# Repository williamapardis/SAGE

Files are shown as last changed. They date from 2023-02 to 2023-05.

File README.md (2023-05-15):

# SAGE

## SAGE ELECTRONICS

- The main SAGE electronics consist of a Red Pitaya FPGA/linux embedded controller, a custom IO PCB, a custom photodiode detector PCB, and a BME280 PCB.
- The Red Pitaya's main fuction is to provide the laser modulation signal and acquire the photodiode signal.
- The custom IO PCB has the following functions:
  - Power regulation for input voltage (usually 24V), 12V, 5V.  All are reverse protected to 40V.  Overcurrent protected. Can take input 12.1-50V.
  - Power switching on 8 channels.  PWM voltage control for each channel.
  - Two i2c pressure sensors.
  - Supplies power to laser and Red Pitaya.
  - Serial communication to Red Pitaya.
  - ESP32 microcontroller - onboard ADCs read thermistors, one onbaord DAC controls laser temperature, one onboard DAC can modulate laser (not preferred), DIO switches power channels, talks to PWM controllers for power modulation (16 on one chip, only using 8), gets time from clock, interfaces with SD Card.
-  The photodiode board contains a photodiode and a dual stage amplifier.  Amplifier resistance and capacitance can be tuned to adjust gain and filtering.
-  A custom PCB for the BME280 contains only a BME 280 on a small circular board.
     
## Custom PCBs

### [SAGE_IO PCB 17-0010](https://github.com/williamapardis/SAGE_IO/tree/main/electrical/SAGE/17-%200010%20ESP32-S3%20Control%20IO)
<table>
  <tr>
    <td>Full View PCB</td>
     <td>Zoomed View</td>
  </tr>
  <tr>
    <td></td>
    <td></td>
  </tr>
</table>

#### Load Control Voltage Selection


### [SAGE Detect PCB](https://github.com/williamapardis/SAGE/tree/main/electrical/SAGE/17-0001%20SAGE%20DETECT) 
<table>
  <tr>
    <td>Full View PCB</td>
     <td>Zoomed View</td>
  </tr>
  <tr>
    <td></td>
    <td></td>
  </tr>
</table>

### RP Adaptor PCB
<table>
  <tr>
    <td>Full View PCB</td>
     <td>Zoomed View</td>
  </tr>
  <tr>
    <td></td>
    <td></td>
  </tr>
</table>

### BME280 PCB
<table>
  <tr>
    <td>Full View PCB</td>
     <td>Zoomed View</td>
  </tr>
  <tr>
    <td></td>
    <td></td>
  </tr>
</table>

## Software

### Set Commands

#### Set Load -> SL#:$$ 
#  = 1-8 FETS
$$ = 0-1 %

#### Set Time (two options)
  sync NTP (current servers: "time.nist.gov", "0.pool.ntp.org", "1.pool.ntp.org")
    SN
  manually
    ST:YYYYMMDD:hhmmss
    
####
    
## Get Commands

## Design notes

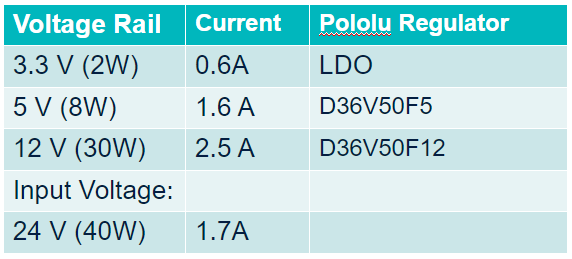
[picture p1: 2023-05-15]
electrical/SAGE/17- 0010 ESP32-S3 Control IO/import/overall totals.png

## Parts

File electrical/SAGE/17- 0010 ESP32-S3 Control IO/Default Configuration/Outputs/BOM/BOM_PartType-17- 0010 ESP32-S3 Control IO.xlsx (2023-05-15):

Quantity | Manufacturer Part # | Manufacturer | Do Not Install | Designator | Vendor | Vendor Part Number | Value | Footprints | Description
1 | DS3231S#T&R | Maxim |  | U9 |  |  |  |  | Real-Time Clock
2 | LMP2011MFX/NOPB | Texas Instruments |  | U8, U10 |  |  |  |  | Single, High Precision, Rail-to-Rail Output Operational Amplifier
1 | MAX6045BEUR | Analog Devices Inc./Maxim Integrated |  | U7 |  |  |  |  | Voltage References Precision, Low-Power, Low-Dropout, SOT23-3 Voltage References
1 | PCA9685PW,112 | NXP USA |  | U6
1 | QT PY ESP32-S3 |  | DNI | U4 | Adafruit | 5426 |  |  | WiFi Dev Board with STEMMA QT - 8 MB Flash / No PSRAM
1 | MCP4728-E/UN | Microchip |  | U3
2 | MPRLS0300YG00001B | Honeywell |  | U2, U5
1 | AP2112K-3.3TRG1 | Diodes Incorporated |  | U1 |  |  |  |  | IC REG LINEAR 3.3V 600MA SOT25
1 | ERJ-PB3B1302V | Panasonic Electronic Components |  | R11 |  |  | 13k | 0603 | Resistor, 0.1%, 1/5W
1 | ERA-3AEB163V | Panasonic Electronic Components |  | R10 |  |  | 16k | 0603 | Resistor, 0.1%, 1/10W
12 | AC0402FR-7W10KL | YAGEO |  | R3, R4, R5, R6, R7, R8, R9, R12, R21, R22, R23, R24 |  |  | 10k | 0402 | RES 10 KOHM 1% 1/8W 0402
1 | SR0402FR-7T4K7L | YAGEO |  | R2 |  |  | 4.7k | 0402 | RES 4.7K OHM 1% 1/5W 0402
9 | SR0603FR-7T100KL | YAGEO |  | R1, R13, R14, R15, R16, R17, R18, R19, R20 |  |  | 100K | 0603 | RES 100K OHM 1% 1/4W 0603
8 | BUK98150-55A/CUF | Nexperia USA |  | Q1, Q2, Q3, Q4, Q5, Q6, Q7, Q8 |  |  |  |  | N-MOSFET N-CH 55V 5.5A SOT223
1 | D36V28F5 | Pololu |  | P17 | Pololu | D36V28F5 |  |  | 5V, 3.2A Step-Down Voltage Regulator
2 | 68000-103HLF | Amphenol ICC (FCI) |  | P15, P16 |  |  |  |  | Header, 3-Pin
8 | 67997-206HLF | Amphenol ICC (FCI) |  | P7, P8, P9, P10, P11, P12, P13, P14 |  |  |  |  | Header, 3-Pin, Dual row
1 | 0022057045 | Molex |  | P6 |  |  |  |  | Connector Header Through Hole, Right Angle 4 position 0.098" (2.50mm)
1 | BM15B-SRSS-TB(LF)(SN) | JST Sales America Inc. |  | P5 |  |  |  |  | Header, 15-Pin
1 | D36V50F5 | Pololu |  | P4 | Pololu | D36V50F5 |  |  | 12V, 4.5A Step-Down Voltage Regulator5V, 5.5A Step-Down Voltage Regulator
1 | D36V50F12 | Pololu |  | P3 | digikey | 2183-4095-ND |  |  | DC DC CONVERTER 12V 54W
1 | 0430451227 | Molex |  | P2 |  |  |  |  | CONN HEADER VERT 12POS 3MM
1 | 0430450827 | Molex |  | P1 |  |  |  |  | CONN HEADER VERT 8POS 3MM
1 | 5031821852 | Molex |  | J15 |  |  |  |  | 10 (8 + 2) Position Card Connector Secure Digital - microSDâ„¢ Surface Mount, Right Angle Gold
8 | 0430450226 |  |  | J5, J6, J7, J8, J9, J10, J11, J12 |  |  |  |  | CONN HEADER VERT 2POS
2 | SM04B-SRSS-TB(LF)(SN) | JST Sales |  | J3, J4
5 | BM04B-SRSS-TB(LF)(SN) | JST Sales |  | J1, J2, J13, J14, J16
1 | NSR0320MW2T1G | onsemi |  | D9 |  |  |  |  | DIODE SCHOTTKY 20V 1A SOD323
8 | S1MLHRVG | Taiwan Semiconductor |  | D1, D2, D3, D4, D5, D6, D7, D8 |  |  |  |  | DIODE GEN PURP 1KV 1A SMA
2 | CC0603KRX7R0BB103 | YAGEO |  | C14, C15 |  |  | 10nF | 0603 | CAP CER 10000PF 100V X7R 0603
1 | CC0603KRX7R0BB222 | YAGEO |  | C13 |  |  | 2.2nF | 0603 | CAP CER 2200PF 100V X7R 0603
2 | CC0603KPX7R9BB104 | YAGEO |  | C4, C8 |  |  | 0.1uF | 0603 | CAP CER 0.1UF 50V X7R 0603
2 | AC0603KRX7R8BB105 | YAGEO |  | C2, C12 |  |  | 1uF | 0603 | CAP CER 1UF 25V X7R 0603
8 | CC0603KRX5R7BB106 | YAGEO |  | C1, C3, C5, C6, C7, C9, C10, C11 |  |  | 10uF | 0603 | CAP CER 10UF 16V X5R 0603
1 | BK-917 | MPD |  | BT |  |  |  |  | BATTERY RETAINER COIN PC PIN

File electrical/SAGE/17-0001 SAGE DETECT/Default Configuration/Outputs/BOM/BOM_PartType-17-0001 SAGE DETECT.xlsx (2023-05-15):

Do Not Install | Quantity | Designator | Manufacturer | Manufacturer Part # | Value | Description | Vendor | Vendor Part #
 | 5 | C1, C2, C3, C9, C10 |  | CC0402MRX6S7BB225 | 2.2uF | 2.2 µF ±20% 16V Ceramic Capacitor X6S 0402 (1005 Metric)
 | 1 | C4 |  | CC0402MRX6S5BB475 | 4.7uF | 4.7 µF ±20% 6.3V Ceramic Capacitor X6S 0402 (1005 Metric)
 | 1 | C5 |  | CC0402KPX5R8BB105 | 1uF | 1 µF ±10% 25V Ceramic Capacitor X5R 0402 (1005 Metric)
 | 1 | C6 | YAGEO | CC0603ZPY5V9BB104 | 100nF | 0.1 µF -20%, +80% 50V Ceramic Capacitor Y5V (F) 0603 (1608 Metric)
DNI | 1 | C7 |  |  | 100pF | Capacitor (Semiconductor SIM Model)
 | 1 | C8 | YAGEO | CC0603JPNPO9BN101 | 100pF | 100 pF ±5% 50V Ceramic Capacitor C0G, NP0 0603 (1608 Metric)
 | 1 | D1 | Lite-On Inc. | LTST-C191TGKT |  | Green 525nm LED Indication - Discrete 3.2V 0603 (1608 Metric)
DNI | 1 | D2
 | 1 | J2 | Linx Technologies Inc. | CONMMCX001-SMD |  | MMCX Connector Receptacle, Female Socket 50Ohm Surface Mount Solder
 | 1 | P1 | JST Sales America Inc. | BM04B-SRSS-TB(LF)(SN) |  | Header, 4-PinConnector Header Surface Mount 4 position 0.039" (1.00mm)
 | 4 | R1, R2, R3, R5 | YAGEO | RT0603BRD07100KL | 100k | 100 kOhms ±0.1% 0.1W, 1/10W Chip Resistor 0603 (1608 Metric) Thin Film
 | 1 | R4 | YAGEO | RT0603BRD07100RL | 100 | 100 Ohms ±0.1% 0.1W, 1/10W Chip Resistor 0603 (1608 Metric) Thin Film
 | 1 | R6 | YAGEO | RT0603BRE0750RL | 50 | 50 Ohms ±0.1% 0.1W, 1/10W Chip Resistor 0603 (1608 Metric) Thin Film
DNI | 2 | R8, R10 |  |  | 100k | Resistor
 | 1 | R9 | YAGEO | RT0603BRD0719K1L | 19.1k | 19.1 kOhms ±0.1% 0.1W, 1/10W Chip Resistor 0603 (1608 Metric) Thin Film
 | 1 | R11 | YAGEO | RC0402FR-070RL | 0 | 0 Ohms Jumper Chip Resistor 0402 (1005 Metric) Moisture Resistant Thick Film
 | 1 | R12 | YAGEO | RT0603BRD071KL | 1k | 1 kOhms ±0.1% 0.1W, 1/10W Chip Resistor 0603 (1608 Metric) Thin Film
 | 1 | U1 | Texas Instruments | LM27762DSSR |  | Charge Pump Switching Regulator IC Positive and Negative (Dual Rail) Adjustable -5V, 1.5V 2 - Dual Output 250mA 12-WFDFN Exposed Pad
 | 1 | U2 | Analog Devices | ADA4528-2ARMZ-R7 |  | Zero-Drift Amplifier 2 Circuit Rail-to-Rail 8-MSOP

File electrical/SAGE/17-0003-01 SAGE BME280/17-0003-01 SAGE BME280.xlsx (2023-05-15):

Manufactuer | Part Number | Description | Designator | Footprint | Voltage | Tollerence | Quantity
Bosch Sensortec | BME280 | SENSOR PRESSURE HUMIDITY TEMP | U1 | SMD |  |  | 1
JST Sales America Inc. | BM04B-SRSS-TB(LF)(SN) | CONN HEADER SMD 4POS 1MM | J1 | SMD

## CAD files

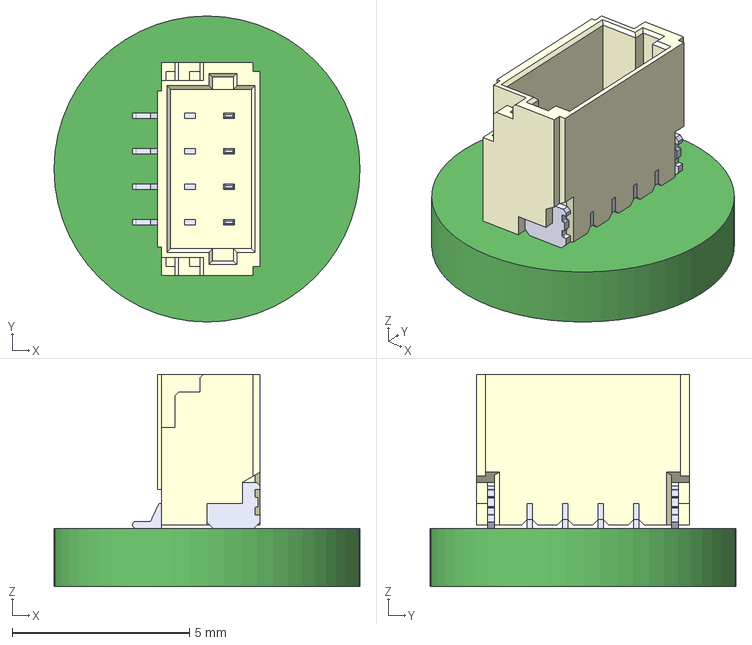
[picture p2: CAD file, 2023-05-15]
electrical/SAGE/17-0003-01 SAGE BME280/Default Configuration/Outputs/ExportSTEP/PCB1.step
8.64 x 8.64 x 6.00 mm
Board
BM04B-SRSS-TB-LF--SN---3DModel-STEP-56544

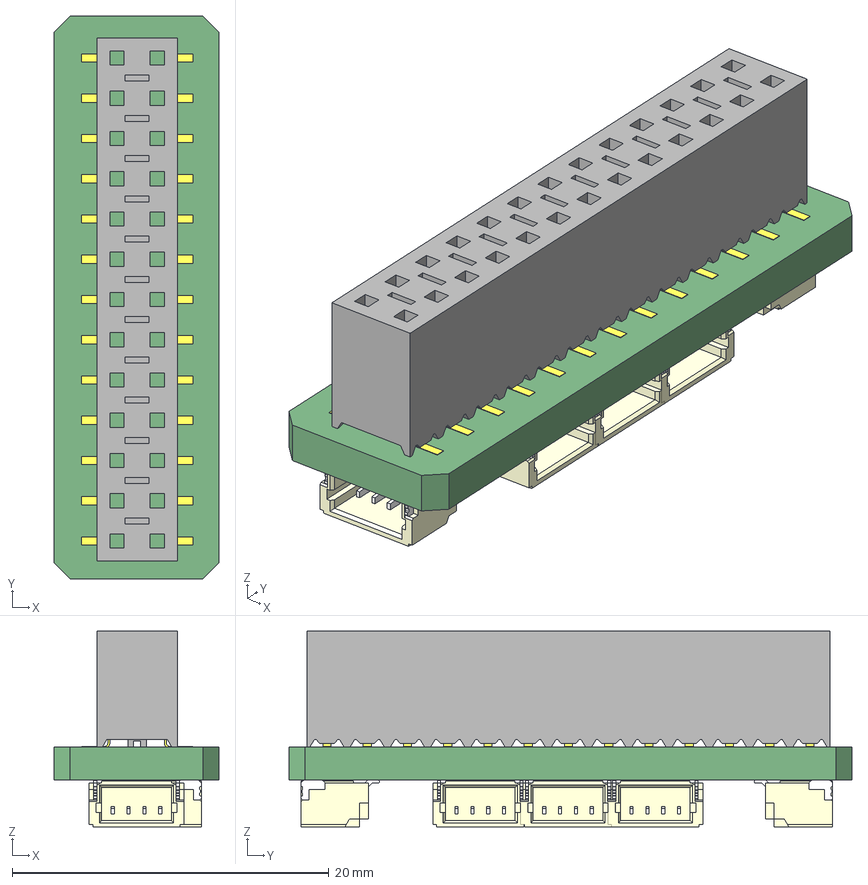
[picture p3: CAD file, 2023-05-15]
electrical/SAGE/Head Adaptor 400-0002/Default Configuration/Outputs/ExportSTEP/PCB1.step
10.4 x 35.5 x 12.4 mm
Board
SM04B-SRSS-TB(LF)(SN)--3DModel-STEP-56544 x 5
C-137-0113
SSM-113-F-DV-LC_body

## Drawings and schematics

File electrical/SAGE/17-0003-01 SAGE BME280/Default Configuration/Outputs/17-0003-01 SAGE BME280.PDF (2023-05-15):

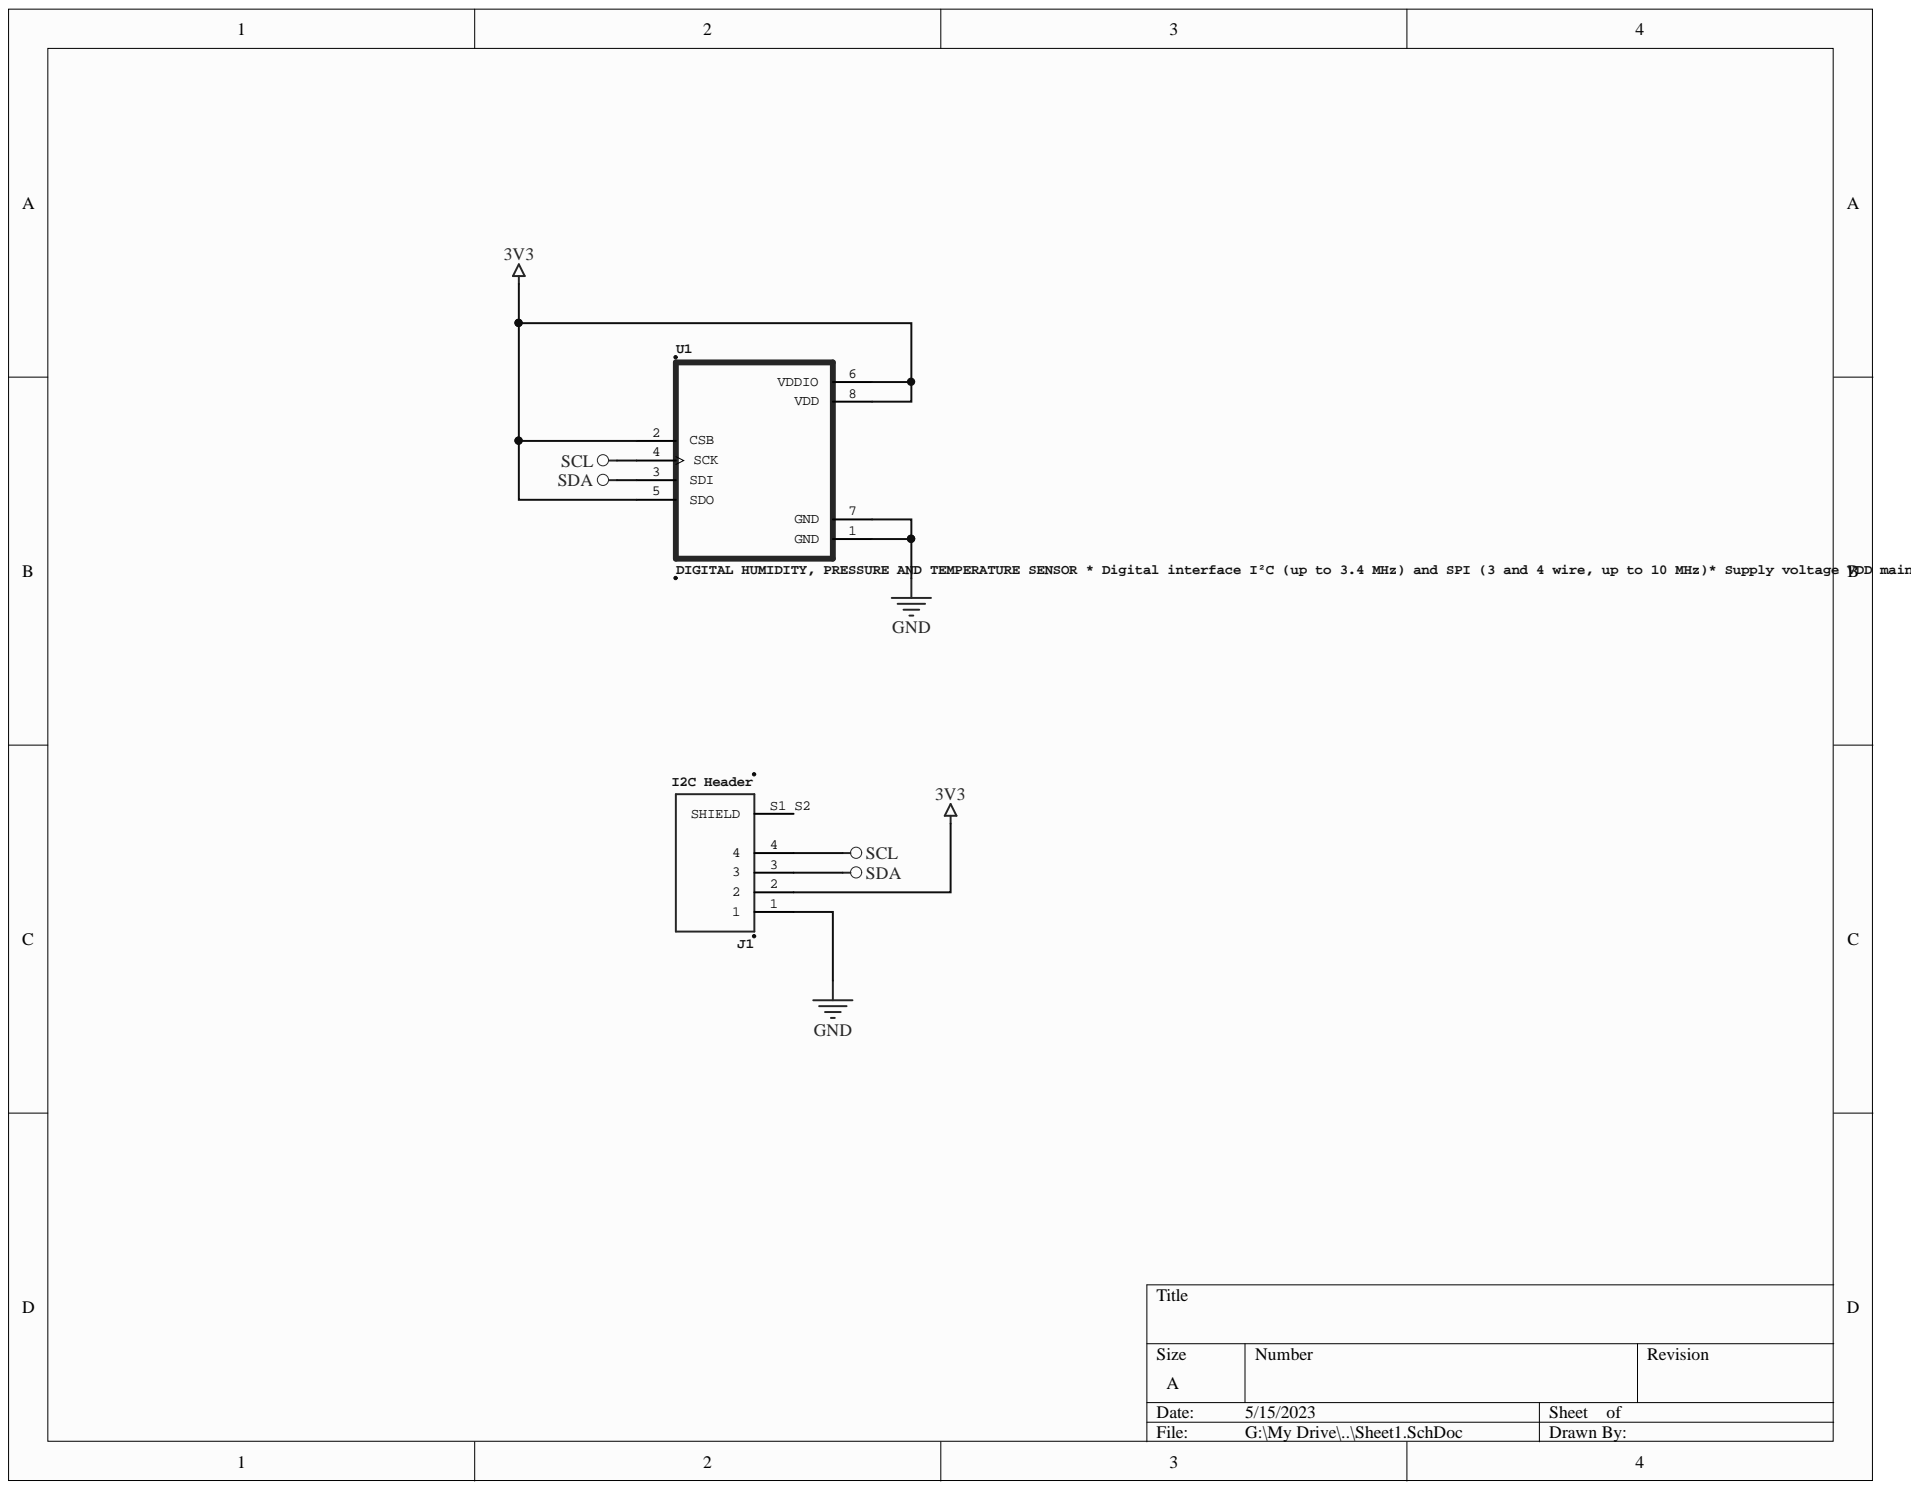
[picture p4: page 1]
Date:; Sheet of; File:; G:\My Drive\..\Sheet1.SchDoc; Drawn By:; CSB 2; SDO 5; SDI 3; SCK 4; DIGITAL HUMIDITY, PRESSURE AND TEMPERATURE SENSOR * Digital interface I²C (up to 3.4 MHz) and SPI (3 and 4 wire, up to 10 MHz)* Supply voltage VDD main supply voltage range: 1.71 V to 3.6 V*VDDIO interface voltage range: 1.2 V to 3.6 V Operating range -40…+85 °C, 0…100 % rel. humidity, 300…1100 hPa; The library has been designed by Richard Magdycz Check availability; SHIELD; I2C Header; PIJ10S1 S2

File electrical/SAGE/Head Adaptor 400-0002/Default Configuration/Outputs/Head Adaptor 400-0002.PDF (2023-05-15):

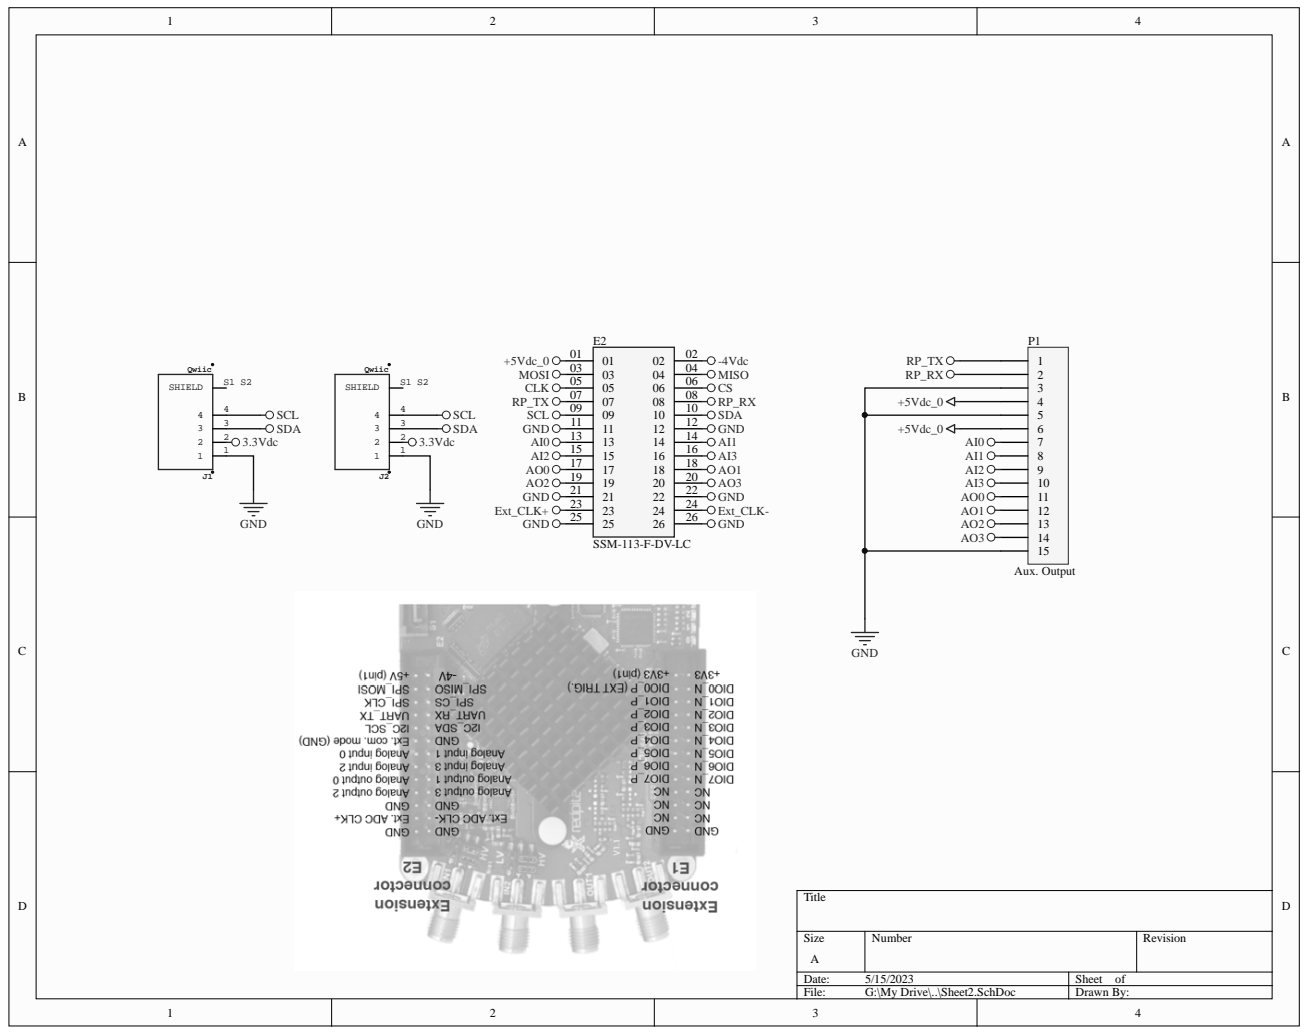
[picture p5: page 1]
+5Vdc_0 MOSI; AI3 AI1 GND; AI0 AI2 AO0 AO2 GND

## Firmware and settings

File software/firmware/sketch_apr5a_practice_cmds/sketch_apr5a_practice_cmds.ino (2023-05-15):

//libraries
#include <Wire.h>
#include <time.h> 
#include "WiFi.h"
#include <Adafruit_TestBed.h>
extern Adafruit_TestBed TB;
//I2C device libraries
#include "RTClib.h"
#include <Adafruit_Sensor.h>
#include <Adafruit_BME280.h>
#include <Adafruit_PWMServoDriver.h>
#include "Adafruit_MPRLS.h"
//SD libraries
#include "FS.h"
#include "SD.h"
#include "SPI.h"

//two different I2C ports
#define DEFAULT_I2C_PORT &Wire
#define SECONDARY_I2C_PORT &Wire1

//time offsets
long timezone = 1; 
byte daysavetime = 1;

//Wifi credentials
const char* ssid = "Scientists2.4";
const char* password = "FalkorTooSC1";

IPAddress IP;

const char* html="<html>"
  "<head>"
  "<meta charset=\"utf-8\">"
  "<title>ESP32-S2 Web control NeoPixel</title>"
  "<meta name=\"viewport\" content=\"width=device-width, initial-scale=1, maximum-scale=1\">"
  "</head>"
  "<body>"
  "Click <a href=\"/H\">here</a> to turn the RGB LED (NeoPixel) ON.<br>"
  "Click <a href=\"/L\">here</a> to turn the RGB LED (NeoPixel) OFF.<br>"
  "</body>"
  "</html>";

// Create AsyncWebServer object on port 80
//AsyncWebServer server(80);
// Set web server port number to 80
WiFiServer server(80);

//DS3231 Real Time Clock
RTC_DS3231 rtc;

//BME280 Pressure Temerpature and Relative Humidity
Adafruit_BME280 bme; // I2C

//PWM driver 
Adafruit_PWMServoDriver pwm = Adafruit_PWMServoDriver();

// You dont *need* a reset and EOC pin for most uses, so we set to -1 and don't connect
#define RESET_PIN  -1  // set to any GPIO pin # to hard-reset on begin()
#define EOC_PIN    -1  // set to any GPIO pin to read end-of-conversion by pin
Adafruit_MPRLS mpr0 = Adafruit_MPRLS(RESET_PIN, EOC_PIN);
// You dont *need* a reset and EOC pin for most uses, so we set to -1 and don't connect
#define RESET_PIN  -1  // set to any GPIO pin # to hard-reset on begin()
#define EOC_PIN    -1  // set to any GPIO pin to read end-of-conversion by pin
Adafruit_MPRLS mpr1 = Adafruit_MPRLS(RESET_PIN, EOC_PIN);

const int BUFFER_SIZE = 100;
char buf[BUFFER_SIZE];


//case structure is organized with commands in alphabetical order by comand syntax
void set(char cmd[]) {
  switch (cmd[1]){

    case 'L':   //setting PWM loads
      if(cmd[3]==':'){
        double duty = atof(&cmd[4]);
        int load = cmd[2]- '0';
        Serial.print("duty clcyle: ");Serial.println(duty);
        if(duty > 1){
          Serial.println("invalid duty cycle, select 0-1");
        }
        else{
          Serial.print("load ");Serial.print(load);Serial.print(" set to: ");Serial.print(duty*100,0);Serial.println('%');
          Serial.println((int)4095*duty);
          pwm.setPWM(load, 0, (int)4095*duty);
        }
      }
    break;

    
    case 'N':   //disconnects AP, connects to local WiFi network, NTP synce, reconnect AP
      WiFi.disconnect();

      ssid = "Scientists2.4";
      password = "FalkorTooSC1";
      
      //First try to connect to WiFi to sync time
      Serial.print("Connecting to: ");
      Serial.print(ssid);
      WiFi.begin(ssid, password);
      while (WiFi.status() != WL_CONNECTED) {
        delay(500);Serial.print(".");
      }
      Serial.println();
      Serial.println("WiFi connected");
      Serial.println("IP address: ");
      Serial.println(WiFi.localIP());
      //collect time from web
      Serial.println("Contacting Time Server");
      configTime(3600*timezone, daysavetime*3600, "time.nist.gov", "0.pool.ntp.org", "1.pool.ntp.org");
      struct tm tmstruct ;
      delay(2000);
      tmstruct.tm_year = 0;
      getLocalTime(&tmstruct, 5000);
      Serial.printf("\nNow is... %d-%02d-%02d %02d:%02d:%02d\n\n",(tmstruct.tm_year)+1900,(tmstruct.tm_mon)+1, tmstruct.tm_mday,tmstruct.tm_hour , tmstruct.tm_min, tmstruct.tm_sec);
      rtc.adjust(DateTime((tmstruct.tm_year)+1900,(tmstruct.tm_mon)+1,tmstruct.tm_mday,tmstruct.tm_hour,tmstruct.tm_min,tmstruct.tm_sec));
      WiFi.disconnect();

      // Setting the ESP as an access point
      Serial.print("Setting AP (Access Point)…");
      ssid = "SAGE-Access-Point";
      password = "WHOI1930";
      // Remove the password parameter, if you want the AP (Access Point) to be open
      WiFi.softAP(ssid, password);

      IP = WiFi.softAPIP();
      Serial.print("AP IP address: ");
      Serial.println(IP);

      server.begin();
    break;

    case 'T':   //manually sets time 
      if(cmd[2]==':'){
        Serial.printf("setting time to %s... ",&cmd[4]);
        rtc.adjust(DateTime(2014, 1, 21, 3, 0, 0));
        Serial.println("time set");
      }
    break;

    case 'A':   //setting analog outputs
      if(cmd[3]==':'){
        double volts = atof(&cmd[4]);
        int out = 4095*(volts/3.3);
        Serial.print("setting A");Serial.print(cmd[2]);Serial.print(":");Serial.println(out);      
        switch(cmd[2]){
          case '0': analogWrite(A0,out); break;
          case '1': analogWrite(A1,out); break;        
        }
      }
    break;        
  }
}

double get(char cmd[]){
  switch (cmd[1]){
    case 'A':   //get analog input
      switch(cmd[2]){
        case '0': return analogRead(A0);
        case '1': return analogRead(A1);
        case '2': return analogRead(A2);
        case '3': return analogRead(A3);
      }
    break;


    case 'P':   //get pressure hPa      
      switch(cmd[2]){
      case '0':
        return mpr0.readPressure();
      break;
      case '1':
        return mpr1.readPressure();
      break;
      case '2':
        return bme.readPressure() / 100.0F;
      break;
      // default:
      //   Serial.print(cmd);Serial.println(" is a invalid command");
      //   return 0;
      // break;
      }
    break;

    case 'I':
      Serial.print("AP IP address: ");
      Serial.println(IP);
      return 1;
    break;
    
    case 'T':
      DateTime now = rtc.now();
      Serial.printf("\nNow is... %d-%02d-%02d %02d:%02d:%02d\n\n",now.year(),now.month(),now.day(),now.hour(),now.minute(),now.second());
      return 1;
    break;
  }
  return 0;
}


void parseCMD(char cmd[]) {
  if(cmd[0]=='S'){
    //read in load number and feed to duty cycle function
    set(cmd);        
  }
  else if(cmd[0]=='G'){
    Serial.println(get(cmd));
  }
}


void wifiIncoming(){
  WiFiClient client = server.available();   // listen for incoming clients
  if (client) {                             // if you get a client,
    Serial.println("New Client.");          // print a message out the serial port
    String currentLine = "";                // make a String to hold incoming data from the client
    while (client.connected()) {            // loop while the client's connected
      if (client.available()) {             // if there's bytes to read from the client,
        char c = client.read();             // read a byte, then
        Serial.write(c);                    // print it out the serial monitor
        if (c == '\n') {                    // if the byte is a newline character

          // if the current line is blank, you got two newline characters in a row.
          // that's the end of the client HTTP request, so send a response:
          if (currentLine.length() == 0) {
            client.print(html);
            // break out of the while loop:
            break;
          } else {    // if you got a newline, then clear currentLine:
            currentLine = "";
          }
        } else if (c != '\r') {  // if you got anything else but a carriage return character,
          currentLine += c;      // add it to the end of the currentLine
        }
        Serial.println(currentLine);
        // Check to see if the client request was "GET /H" or "GET /L":
        if (currentLine.endsWith("GET /H")) {
          Serial.println("\n--- ON ---");
        }
        if (currentLine.endsWith("GET /L")) {
          Serial.println("\n--- OFF ---");
        }

      }
    }
    // close the connection:
    client.stop();
    Serial.println("Client Disconnected.");
  }  
}

void incoming(){
  while(Serial.available()>0){
    Serial.readBytesUntil('\n', buf, BUFFER_SIZE);
    Serial.print("command recieved: ");Serial.println(buf);
    parseCMD(buf);
    memset(buf, 0, BUFFER_SIZE);;
  }
}









void setup() {

  analogReadResolution(12);

  Wire1.setPins(SDA1, SCL1);

  //serial ports init
  Serial.begin(115200);Serial.flush();
  Serial1.begin(115200);Serial1.flush();
  while(!Serial){delay(10000);break;}

  //initilizing clock
  Serial.print("initilizing DS3231, bus 0, addr  ... "); 
  if (!rtc.begin()) {
    Serial.println("Couldn't find RTC");
    Serial.flush();
    while (1) delay(10);
  }
  Serial.println("found DS3231");
  DateTime now = rtc.now();
	Serial.printf("\nNow is... %d-%02d-%02d %02d:%02d:%02d\n\n",now.year(),now.month(),now.day(),now.hour(),now.minute(),now.second());
  
  //initilize SD card
  Serial.print("initilizing SD card... ");
  if(!SD.begin()){
    Serial.println("Card Mount Failed");
  }
  Serial.println("SD initilized");  
  //print storage
  Serial.printf("Total space: %lluMB\n", SD.totalBytes() / (1024 * 1024));
  Serial.printf("Used space: %lluMB\n", SD.usedBytes() / (1024 * 1024));
  //check or creat data diretory 
  //char dataDir[30];
  //sprintf(dataDir,"/data/%d%02d%02dT%02d%02d%02d",(tmstruct.tm_year)+1900,( tmstruct.tm_mon)+1, tmstruct.tm_mday,tmstruct.tm_hour , tmstruct.tm_min, tmstruct.tm_sec);
 
  //createDir(SD,dataDir);
  //list root directory
  //listDir(SD, "/data", 0);


  // Setting the ESP as an access point
  Serial.print("Setting AP (Access Point)…");
  ssid = "SAGE-Access-Point";
  password = "WHOI1930";
  // Remove the password parameter, if you want the AP (Access Point) to be open
  WiFi.softAP(ssid, password);

  IP = WiFi.softAPIP();
  Serial.print("AP IP address: ");
  Serial.println(IP);

  server.begin();


  //Scan I2C bus and print the available addresses
  Serial.println("scanning I2C busses");
  Serial.print("Default port (Wire0) ");
  TB.theWire = DEFAULT_I2C_PORT;
  TB.printI2CBusScan();  
  Serial.print("Secondary port (Wire1) ");
  TB.theWire = SECONDARY_I2C_PORT;
  TB.printI2CBusScan();

  //initilize BME280
  Serial.print("initilizing BME280, bus 1, addr 0x77... "); 
    if (!bme.begin(0x77,&Wire1)) {
        Serial.println("failed");
    }
  Serial.println("found BME280 sensor");
  
  //initilize PWM driver
  Serial.print("initilizing PWM driver, bus 0, addr 0x40... ");
  pwm.begin();
  pwm.setOscillatorFrequency(27000000);
  pwm.setPWMFreq(1600);  // This is the maximum PWM frequency
  Serial.println("PWM driver initilized");

  //initilizing MPRLS pressure sensors
  Serial.print("initilizing MPRLS pressure sensor, bus 0, addr 0x18... ");
  if (! mpr0.begin(0x18,&Wire)) {
    Serial.println("failed");
  }
  Serial.println("found MPRLS sensor");
  Serial.print("initilizing MPRLS pressure sensor, bus 1, addr 0x18... ");
  if (! mpr1.begin(0x18,&Wire1)) {
    Serial.println("failed");
  }
  Serial.println("found MPRLS sensor");

}

//for(int i=0;i<256;i++){
//    dacWrite(17,i);delay(100);Serial.println(i);
//}

void loop() {
  incoming();
  //wifiIncoming();
}

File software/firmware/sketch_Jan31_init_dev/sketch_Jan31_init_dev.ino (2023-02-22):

#include <Wire.h>
#include <Arduino.h>
#include <Adafruit_Sensor.h>
#include <Adafruit_BME280.h>
#include "Adafruit_MPRLS.h"
#include "RTClib.h"

//TwoWire I2Czero = TwoWire(0);
TwoWire I2Cone = TwoWire(1);

//Real time clock DS3231 0x68
RTC_DS3231 rtc;

//Pressure Temperature and Relative Humidity Sensor BME280
Adafruit_BME280 bme; // I2C

// You dont *need* a reset and EOC pin for most uses, so we set to -1 and don't connect 0x18
#define RESET_PIN  -1  // set to any GPIO pin # to hard-reset on begin()
#define EOC_PIN    -1  // set to any GPIO pin to read end-of-conversion by pin
Adafruit_MPRLS mpr1 = Adafruit_MPRLS(RESET_PIN, EOC_PIN);

// You dont *need* a reset and EOC pin for most uses, so we set to -1 and don't connect 0x18
#define RESET_PIN  -1  // set to any GPIO pin # to hard-reset on begin()
#define EOC_PIN    -1  // set to any GPIO pin to read end-of-conversion by pin
Adafruit_MPRLS mpr2 = Adafruit_MPRLS(RESET_PIN, EOC_PIN);

const int SAMPLE_PERIOD = 1000;
const int BUFFER_SIZE = 50;
char buf[BUFFER_SIZE];
float timer,stop;

void setup() {

  //ADC bit resolution setting
  analogReadResolution(12);

  //I2Czero.begin(SDA,SCL);
  Wire.begin();
  I2Cone.begin(SDA1,SCL1);

  Serial.begin(115200);
  //while (!Serial) {
  //    ; // wait for serial port to connect. Needed for native USB port only
  //}
  Serial1.begin(9600);
  Serial.println("Begin");

  //start clock
  if (! rtc.begin(&I2Cone)) {
    Serial.println("Couldn't find RTC");
    Serial.flush();
    while (1) delay(10);
  }
  //set time
  if (rtc.lostPower()) {
    Serial.println("RTC lost power, let's set the time!");
    // When time needs to be set on a new device, or after a power loss, the
    // following line sets the RTC to the date & time this sketch was compiled
    rtc.adjust(DateTime(F(__DATE__), F(__TIME__)));
    // This line sets the RTC with an explicit date & time, for example to set
    // January 21, 2014 at 3am you would call:
    // rtc.adjust(DateTime(2014, 1, 21, 3, 0, 0));
  }

  // default setting
  if (!bme.begin(&I2Cone)) {
    Serial.println("Could not find a valid BME280 sensor, check wiring, address, sensor ID!");
    Serial.print("SensorID was: 0x"); Serial.println(bme.sensorID(),16);
    Serial.print("        ID of 0xFF probably means a bad address, a BMP 180 or BMP 085\n");
    Serial.print("   ID of 0x56-0x58 represents a BMP 280,\n");
    Serial.print("        ID of 0x60 represents a BME 280.\n");
    Serial.print("        ID of 0x61 represents a BME 680.\n");
  }  

  if (! mpr1.begin(0x18,&I2Cone)) {
    Serial.println("Failed to communicate with MPRLS1 sensor, check wiring?");
    while (1) {
      delay(10);
    }
  }

  if (! mpr2.begin()) {
    Serial.println("Failed to communicate with MPRLS2 sensor, check wiring?");
    while (1) {
      delay(10);
    }
  }

  timer = millis();
  
}



void loop() {


    //timing
    if(timer > millis()){timer = millis();}

    
    
    //Serial.println(millis()-timer);
    delay(250);
    
    if(millis() - timer > SAMPLE_PERIOD){
      timer = millis();

      //Convience header
      Serial.println("Time[ISO],BME_T[C],BME_P[hPa],BME_RH[%],MPR1_P[hPa],MPR2_P[hPa],A0[12BIT],A3[12BIT]");

      //Time Aquire
      DateTime now = rtc.now();
      Serial.print(now.year(), DEC);
      Serial.print(now.month(), DEC);
      Serial.print(now.day(), DEC);
      Serial.print("T");
      Serial.print(now.hour(), DEC);
      Serial.print(now.minute(), DEC);
      Serial.print(now.second(), DEC);
      Serial.print(',');

      //BME280 Aquire
      Serial.print(bme.readTemperature());Serial.print(',');
      Serial.print(bme.readPressure() / 100.0F);Serial.print(',');
      Serial.print(bme.readHumidity());Serial.print(',');

      //MPRLS Aquire
      Serial.print(mpr1.readPressure());Serial.print(',');
      Serial.print(mpr2.readPressure());Serial.print(',');

      Serial.print(analogRead(A0));Serial.print(',');
      Serial.print(analogRead(A3));Serial.print(',');

      Serial.println();

      stop = millis();
      Serial.println(timer-stop);
      Serial.println();
      Serial.println();

      
    }
  
}

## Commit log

2023-04-30 about to make some SD functions, incorperated the pressure sensors and IO
2023-05-15 adding PCB fab file
    [17- 0010 ESP32-S3 Control IO.PrjPcb, 17-0001 SAGE DETECT.PrjPcb, 17-0003-01 SAGE BME280.PrjPcb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]
2023-05-15 added header PCB and some schematics
    [Head Adaptor 400-0002.PrjPcb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]
